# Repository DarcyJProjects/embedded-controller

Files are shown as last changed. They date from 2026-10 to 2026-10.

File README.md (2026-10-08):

# Industrial Automation Embedded Controller

### Introduction

This project was a deep dive into 4-layer PCBs, galvanic isolation, strict EMI filtering, and mixed-signal design with the goal to create a robust, industrial-style controller from scratch.

Built around an STM32 Cortex-M4, this embedded controller handles galvanically isolated field I/O using a custom DMA-driven MODBUS RTU stack. It also features a "no-code" automation engine, letting you configure logic remotely via a web panel.

I've implemented several hardware features including an RTC with battery backup, HMI OLED, microSD logging, an EEPROM, efficient multi-stage power distribution & conversion with real time power monitoring, as well as many protection features.

The entire project - the custom PCB, schematics, firmware, and web panel - is completely open-source, so feel free to look into it and see how it works!

IMG: Main

<p>
  This project is open source hardware under the <strong>CERN Open Hardware Licence Version 2 - Strongly Reciprocal (CERN-OHL-S v2)</strong>.
</p>
Open Source Hardware Logo

The editable hardware source files are provided so that the design can be studied, modified, and manufactured in accordance with the licence.

⚖️**Disclaimer:** *This hardware is a personal engineering project created solely for **educational purposes and skill development**. While it explores industrial design techniques, it has not been tested against or certified for any specific industrial standards (e.g., IEC, UL, CE). It is provided ”AS IS” without warranty. For full licence details, design files, and terms of use, please see the **[licence section of this document](#licence)**.*

---

## Table of Contents

* [Demo](#demo)

* [Features & Specifications](#features--specifications)

* [Hardware Architecture & Schematics](#hardware-architecture--schematics)

* [How It Works](#how-it-works)

* [Why I Built This](#why-i-built-this)

* [Firmware & Web Panel](#firmware--web-panel)

* [Repo Structure](#repo-structure)

* [Licence](#licence)

* [Safety Disclaimer](#safety-disclaimer)

* [Acknowledgements](#acknowledgements)

* [Feedback & Contributions](#feedback--contributions)

---

## Demo

For the demo, I mounted the controller on a DIN rail and wired it into a small irrigation-style test rig. The goal was to demonstrate as many parts of the board as possible, including relay outputs, digital inputs, analogue voltage signals, 4-20 mA current loops, and MODBUS-based monitoring/control.

Watch Here ➡️: [STM32 Embedded Controller Demo - YouTube](https://www.youtube.com/watch?v=2GqDx222arY)

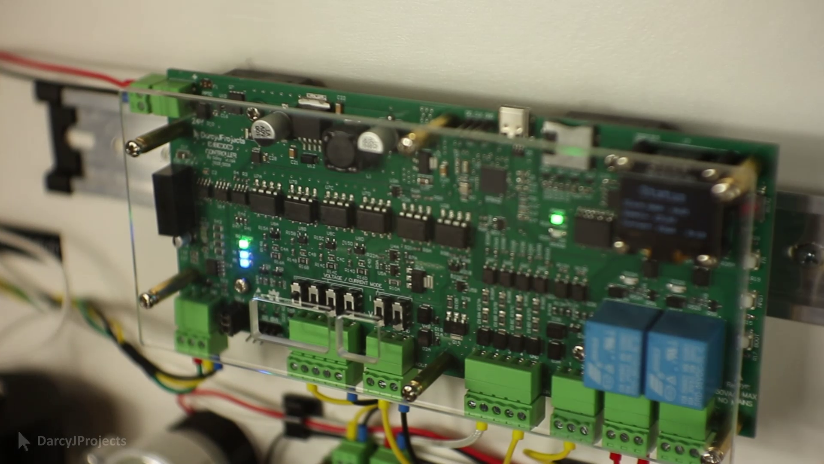
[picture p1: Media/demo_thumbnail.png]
IMG: PCB


I also designed a 4-20 mA transmitter board for this demo converting a 0-3.3V signal to a current loop: [Designing a 4-20 mA Transmitter - DarcyJProjects](https://darcyjprojects.xyz/index.php/2026/05/25/designing-a-4-20-ma-transmitter/)

---

## Features & Specifications

I tried to pack a wide range of industrial-style hardware and firmware features into this controller so I could learn as much as possible across the realms of PCB design, embedded firmware, power electronics, isolation, and automation protocols.

IMG: PCB

### **Core Specifications:**

- **Core:** STM32G431 Cortex-M4 MCU running at up to 170 MHz
- **Power input:** 7-28 V DC input range
- **PCB:** Custom 4-layer PCB with separated logic and field domains
- **Protection:** Reverse polarity protection, over-current protection, TVS protection, and ESD protection
- **Isolation:** Galvanic isolation between the logic side and field-side interfaces
- **Memory:** 4 KB EEPROM with CRC-backed configuration and automation rule storage
- **Connectivity:** Isolated RS485 for MODBUS RTU, plus USB-C for DFU flashing and serial debugging
- **Control:** Web panel with custom "no-code" automation rules and MODBUS register access
- **Local interface:** OLED display, tactile buttons, status LEDs, and hardware mode switches, on-board configuration factory reset
- **Expansion:** Isolated I²C header for supported field-side peripherals

**A more detailed outline can be found in the 10-page datasheet [here](https://github.com/DarcyJProjects/embedded-controller/blob/main/Documentation/datasheet/datasheet.pdf).**

### Isolated Field I/O:

| Interface | Channels | Electrical Specification | Description |
|:--- |:---:|:--- |:--- |
| **Analogue Inputs** | 4 | 0–5 V or 4–20 mA | 12-bit ADC; Per channel switch for Voltage & Current Mode |
| **Analogue Outputs** | 2 | 0–5 V or 4–20 mA | 12-bit DAC; Per channel switch for Voltage & Current Mode |
| **Digital Inputs** | 4 | 24 V DC signalling | Optocoupler-isolated industrial binary inputs |
| **Digital Outputs** | 2 | 24 V DC load rated | Galvanically isolated low-side sinking drivers |
| **Relay Outputs** | 2 | 30 V DC / 50 V AC (ELV)  | SPDT mechanical relays |
| **I²C expansion header** | 1 | Isolated 3.3 V / 5 V I²C | Allows supported external devices to be mapped into the MODBUS register space with custom firmware drivers |

### Power:

- Buck Converter for High Efficiency 24 V to 5 V conversion
- Linear Regulator for a clean 3.3 V supply to the MCU
- Switching Isolation Power Supply to power the field side circuitry
- PPTC Fuses, "Ideal Diode" Reverse Polarity Protected Input

### On Board HMI:

- 0.96" OLED display
- 4x tactile buttons for menu navigation, reset, DFU entry, and factory reset
- Status LEDs for power, isolated power, communication, relay state, and general status
- Hardware mode switches for analogue current/voltage configuration

### Overall Block Diagram:

IMG: Block diagram

### Power Supply Block Diagram:

IMG: Power Supply Block Diagram

---

## Hardware Architecture & Schematics

To maintain readability and to provide reusability of designs, the hardware is structured hierarchically in Altium Designer rather than using a single flat schematic.

### Hierarchical Design Breakdown

The design is partitioned into 1 top-level sheet and 15 modular sub-sheets:

- **Main:** Connects all subsheets together, reuses I/O designs for multiple channels, and attaches connectors.
  
  - **I2C_Isolator:** I2C header with ISO1540 isolator, TVS protection
  
  - **AOut_Isolator:** Reusable 3.3V to isolated 0-5V/4-20mA analogue output channel with NSI1200 isolator, TVS protection
  
  - **DOut_Isolator:** Reusable 3.3V to sinking 24V digital output channel with LTV-356T optoisolator, TVS protection
  
  - **I2C_RTC_DS3231:** On-board DS3231 Real Time Clock and clock battery
  
  - **AIN_Isolator:** Reusable isolated 0-5V/4-20mA analogue to 3.3V input channel with NSI1200 isolator, TVS protection
  
  - **STM32_MCU:** STM32G431CBU6 microcontroller with USB DFU, filtering, SWD, status LEDs and BOOT & NRST buttons. TVS diodes on USB & SWD lines
  
  - **Power_Supply:** PPTC Fused 24V input through "ideal diode" reverse polarity protection through 24 to 5V buck converter, branching to 3.3V linear regulator for logic side power and a PPTC fused 5V DC-DC isolation power supply for the field side. Features TVS diodes on 24V input and 5V field side output of DC-DC converter
  
  - **RS485:** MAX485 Transceiver with dual CA-IS3722 Isolators, status LEDs, biasing and termination header, TVS protection
  
  - **I2C_PowerMonitor_INA226:** INA226 power monitoring IC for the 24V input post reverse polarity protection but pre buck converter
  
  - **I2C_EEPROM_AT24C32:** AT24C32BN EEPROM used for automation rule and configuration storage
  
  - **I2C_Display:** Socket for the 0.96 inch OLED display module, Menu button
  
  - **BTN2_FactoryReset:** Factory reset button
  
  - **SPI_SD:** MicroSD card slot with TVS protection on all data lines
  
  - **DOut_Relay:** Reusable SPDT relay with coil switched to isolated 5V supply via LTV-356T optoisolator, status LED, flyback suppression
  
  - **DIn_Isolator:** Reusable 24V to 3.3V digital input channel with LTV-356T optoisolator, TVS protection

**Schematics:** View the complete 16-sheet schematic here: [Documentation/schematics](https://github.com/DarcyJProjects/embedded-controller/blob/main/Documentation/schematics.pdf)

### Galvanic Isolation Separation

The PCB features a continuous galvanic isolation barrier running through all 4 layers:

- **Domain Partitioning:** The logic ground (`GND`) and the isolated field ground (`5V_ISO_GND`) are never connected together nor overlap or share ground planes.

- **Physical Barrier:** A continuous non-copper clearance barrier splits the PCB in two from top to bottom, offering the logic side a protective barrier from field side HV transients.

- **Over the Barrier:** No traces cross the barrier without isolation by dedicated isolation ICs or optoisolators.

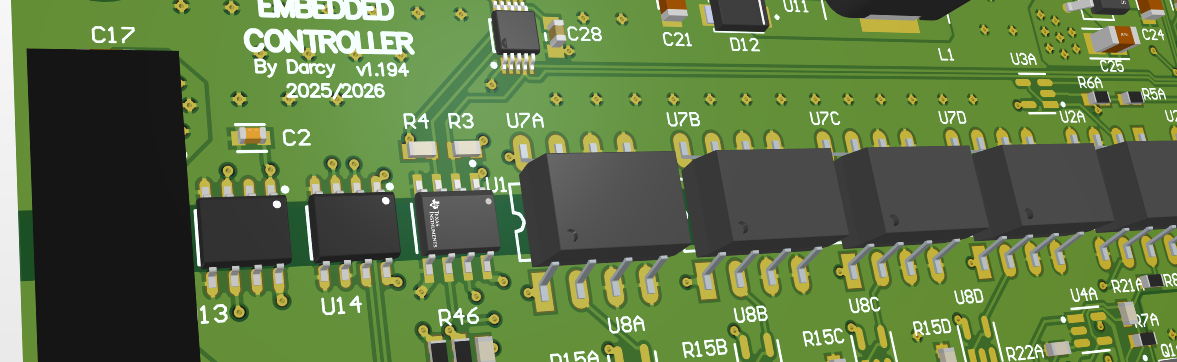
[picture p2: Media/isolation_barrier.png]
Isolation Barrier Image


---

## How It Works

The controller is split into two main electrical domains:

1. **Logic Domain:** STM32G4 MCU, EEPROM, OLED, RTC, buttons, USB-C DFU, isolated signals coming from the I/O isolators, etc.

2. **Field Domain:** I/O Inputs and Outputs, Relays, RS485, Isolated I²C expansion header

These two domains are separated by a galvanic isolation barrier. If you look at the PCB, you can actually see a moat separating the two sides copper pours.

The field side is powered through an isolated 5V DC/DC converter, and the signals that cross the barrier use appropriate isolators depending on the interface (capacitive, optical, etc).

### MODBUS register model

The firmware exposes the controller's I/O through a MODBUS register map:

- **Discrete inputs** for digital input states
- **Coils** for digital outputs and relay outputs
- **Input registers** for analogue input readings
- **Holding registers** for analogue output setpoints

There are also **virtual registers**, which can be created dynamically and used as intermediate values in the automation logic. This is useful for when you need to link many rules together for more complex automation logic.

### Custom automation engine

One of the main firmware features is the local automation engine. Instead of reflashing the STM32 every time you want to update its configuration or more importantly its automation logic, rules can be configured directly over MODBUS using custom vendor-defined (that's me!) function codes.

The idea is to make the board behave a little more like a tiny configurable PLC. A rule can read an input, compare a value, update an output, or write to a virtual register. Once configured, the STM32 runs the logic locally.

### Hybrid MODBUS master/slave concept

The firmware is also designed around a hybrid MODBUS architecture allowing the controller to act as both a master and slave at the same time. The controller can report data to an upstream system while also communicating with downstream MODBUS devices.

For instance, [I reverse engineered an RS485 SHT30 sensor](https://darcyjprojects.xyz/index.php/2025/07/08/reverse-engineering-a-cheap-sht30-rs485-modbus-sensor/) used for reading temperature and humidity. By connecting this to the RS485 line of the embedded controller, it can read from the sensor over MODBUS (as a master to the slave sensor) while also reporting information requested back to the web panel (as a slave to the master web panel). 

This was mainly an experiment in building something more flexible than a fixed slave board, while still keeping the system simple enough to understand and debug.

IMG: Web Panel

---

## Why I Built This

This project was a major undertaking compared to my earlier electronics projects, integrating mixed signal design, complex isolation barriers, and low level C protocol implementation. I wanted to build something that forced me to deal with more realistic embedded hardware problems, relevant to industrial, mining, manufacturing and remote monitoring environments.

### What I learnt: hardware

- 4-layer PCB design
- Altium Designer workflow
- Mixed-signal PCB layout
- Analogue and digital galvanic isolation
- Isolated power supply design
- 24 V field input and output circuitry
- 4-20 mA current-loop inputs and outputs
- RS485 physical-layer design, termination, and biasing
- Relay output design and low-side switching
- Protection circuitry using PPTC fuses, TVS diodes, and MOSFET-based reverse polarity protection
- Rail-to-rail op-amp circuits for buffering, scaling, and signal conditioning
- Debugging real PCB mistakes using trace cuts, enamel wire, and a lot of patience
- Parasitic impedance and what it does to buck converters!

### **What I learnt: Software**

- STM32CubeIDE and STM32G4 firmware development
- Writing a MODBUS RTU stack from scratch
- Using DMA so communication does not block the CPU
- Building drivers for EEPROMs, RTCs, OLEDs, and other peripherals
- Storing configuration data with CRC checks
- Designing a small rule engine for local automation logic
- Mapping physical and virtual I/O into a MODBUS register model
- Building a Node.js web panel to configure and monitor an embedded device
- How to use LaTeX to write documentation

IMG: Prototyping

---

## Firmware & Web Panel

### Firmware Flashing

The firmware is built in STM32CubeIDE for the STM32G431CBU6 and can be uploaded to the Embedded Controller via the USB-C port:

1. Ensure the board is powered via an external 24V DC supply. The USB connector provides no power, so the external supply is necessary.
2. Connect to the board using a USB-C cable.
3. Enter the bootloader by holding `BOOT0` , pressing/pulsing `NRST` once, and then finally releasing `BOOT0`.
4. Flash the compiled binary directly over USB DFU using STM32CubeProgrammer or a similar utility.
5. Connect over serial/MODBUS via the RS485 line for configuration.

### Web panel

The Node.js web panel connects via a USB-to-RS485 adapter to interface with the embedded controller over MODBUS. It can be installed like so:

```bash
cd "Web Panel"
npm install
npm start
```

Open the local address shown in the terminal in a web browser. Connect to the RS485 line with a USB-to-RS485 converter and select its Serial COM port.

---

## Repo Structure

```text
stm32-plc-project/
├── Documentation/              # Datasheet, drawings, PDF Schematics
├── Firmware/                   # STM32CubeIDE firmware project
├── Hardware/                   # Altium Designer project: PCB design files, Altium schematics
├── Web Panel/                  # Node.js web configuration panel
├── Media/                      # Photos, renders, screenshots, and demo images
├── LICENCE-CERN-OHL-S-2.0.txt  # CERN-OHL-S v2 licence text for hardware
├── LICENCE-MIT.txt             # MIT licence text for software
└── README.md                   # this file!
```

---

## Licence

This repository contains both hardware design files and software.

### Hardware

The hardware design files are licenced under the **CERN Open Hardware Licence Version 2 - Strongly Reciprocal (CERN-OHL-S v2)**.

This applies to the PCB design files, schematics, hardware source files, mechanical drawings, and other files required to study, modify, manufacture, and distribute the hardware design.

You are free to:

- **Study** and **modify** the design
- **Make** your own copies
- **Distribute** modified versions, as long as you follow the licence terms

In general, the strongly reciprocal licence means that modified versions of the covered hardware design must also be shared under the same licence, with attribution and source files provided.

For the full legal terms, see [LICENCE-CERN-OHL-S-2.0.txt](https://github.com/DarcyJProjects/embedded-controller/blob/main/LICENCE-CERN-OHL-S-2.0.txt).

### Firmware and Software

Unless otherwise stated, the firmware and software in this repository are licenced under the **MIT Licence**.

This applies to the STM32 firmware and the web configuration panel.

For the full legal terms, see [LICENCE-MIT.txt](https://github.com/DarcyJProjects/embedded-controller/blob/main/LICENCE-MIT.txt).

### Third-Party Code and Resources

Some parts of this project make use of third-party open-source code and resources. These remain under their original licences and are acknowledged in the [Acknowledgements](#acknowledgements) section.

IMG: Close up

---

## Safety Disclaimer

This hardware is a personal engineering project created solely for educational purposes, experimentation, and skill development.  

Although it uses industrial-style design techniques, it has **not** been tested, approved, certified, or validated against industrial, safety, EMC, electrical, environmental, functional safety, or regulatory standards, including IEC, UL, CE, RCM, or any similar certification scheme.  

**LIMITATION OF LIABILITY:**

**THIS PROJECT IS PROVIDED "AS IS", WITHOUT WARRANTY OF ANY KIND, EXPRESS OR IMPLIED. TO THE MAXIMUM EXTENT PERMITTED BY LAW, THE COPYRIGHT HOLDER ACCEPTS NO LIABILITY FOR ANY DAMAGE, INJURY, DEATH, LOSS, NON-COMPLIANCE, EQUIPMENT FAILURE, DATA LOSS, BUSINESS INTERRUPTION, OR ANY OTHER ISSUE RESULTING FROM THE USE, MODIFICATION, MANUFACTURE, ASSEMBLY, DISTRIBUTION, OR ATTEMPTED DEPLOYMENT OF THIS DESIGN.**

Do **not** use this project in:  

- real industrial installations  
- safety-critical systems  
- mains-voltage systems  
- life-support, medical, automotive, aviation, mining, or hazardous environments  
- commercial products without proper engineering review, testing, certification, and regulatory approval  
- any system where failure could cause injury, property damage, environmental harm, financial loss, or unsafe operation  

Anyone using, modifying, manufacturing, or testing this design does so entirely at their own risk and is responsible for ensuring compliance with all applicable laws, standards, and safety requirements.

---

## Acknowledgements

- The datasheet for this project was created using the [LaTeX Datasheet Template by Petteri Aimonen](https://github.com/PetteriAimonen/latex-datasheet-template), which is licenced under the LPPL-1.3c licence.

- The firmware directly uses the [stm32-ssd1306 OLED display driver by afiskon](https://github.com/afiskon/stm32-ssd1306) for the SSD1306-based OLED display, which is licenced under the MIT licence.

- The MicroSD / FatFS implementation was helped by this tutorial kiwih: [An SD card over SPI using STM32CubeIDE and FatFS](https://01001000.xyz/2020-08-09-Tutorial-STM32CubeIDE-SD-card/).

- Some parts of the firmware were written early in the project while the hardware was still being tested on breadboards. I have tried to acknowledge all external resources used, but if I have missed anything, please let me know and I will be happy to add the appropriate credit.

---

### Feedback & Contributions

Feel free to fork, share, and build your own!

If you build one, adapt part of the design, or use it to help with one of your own projects, I would love to see it - tag me on [LinkedIn](https://www.linkedin.com/in/darcywdjohnson/).

---

Darcy @ [www.darcyjprojects.xyz](https://www.darcyjprojects.xyz)

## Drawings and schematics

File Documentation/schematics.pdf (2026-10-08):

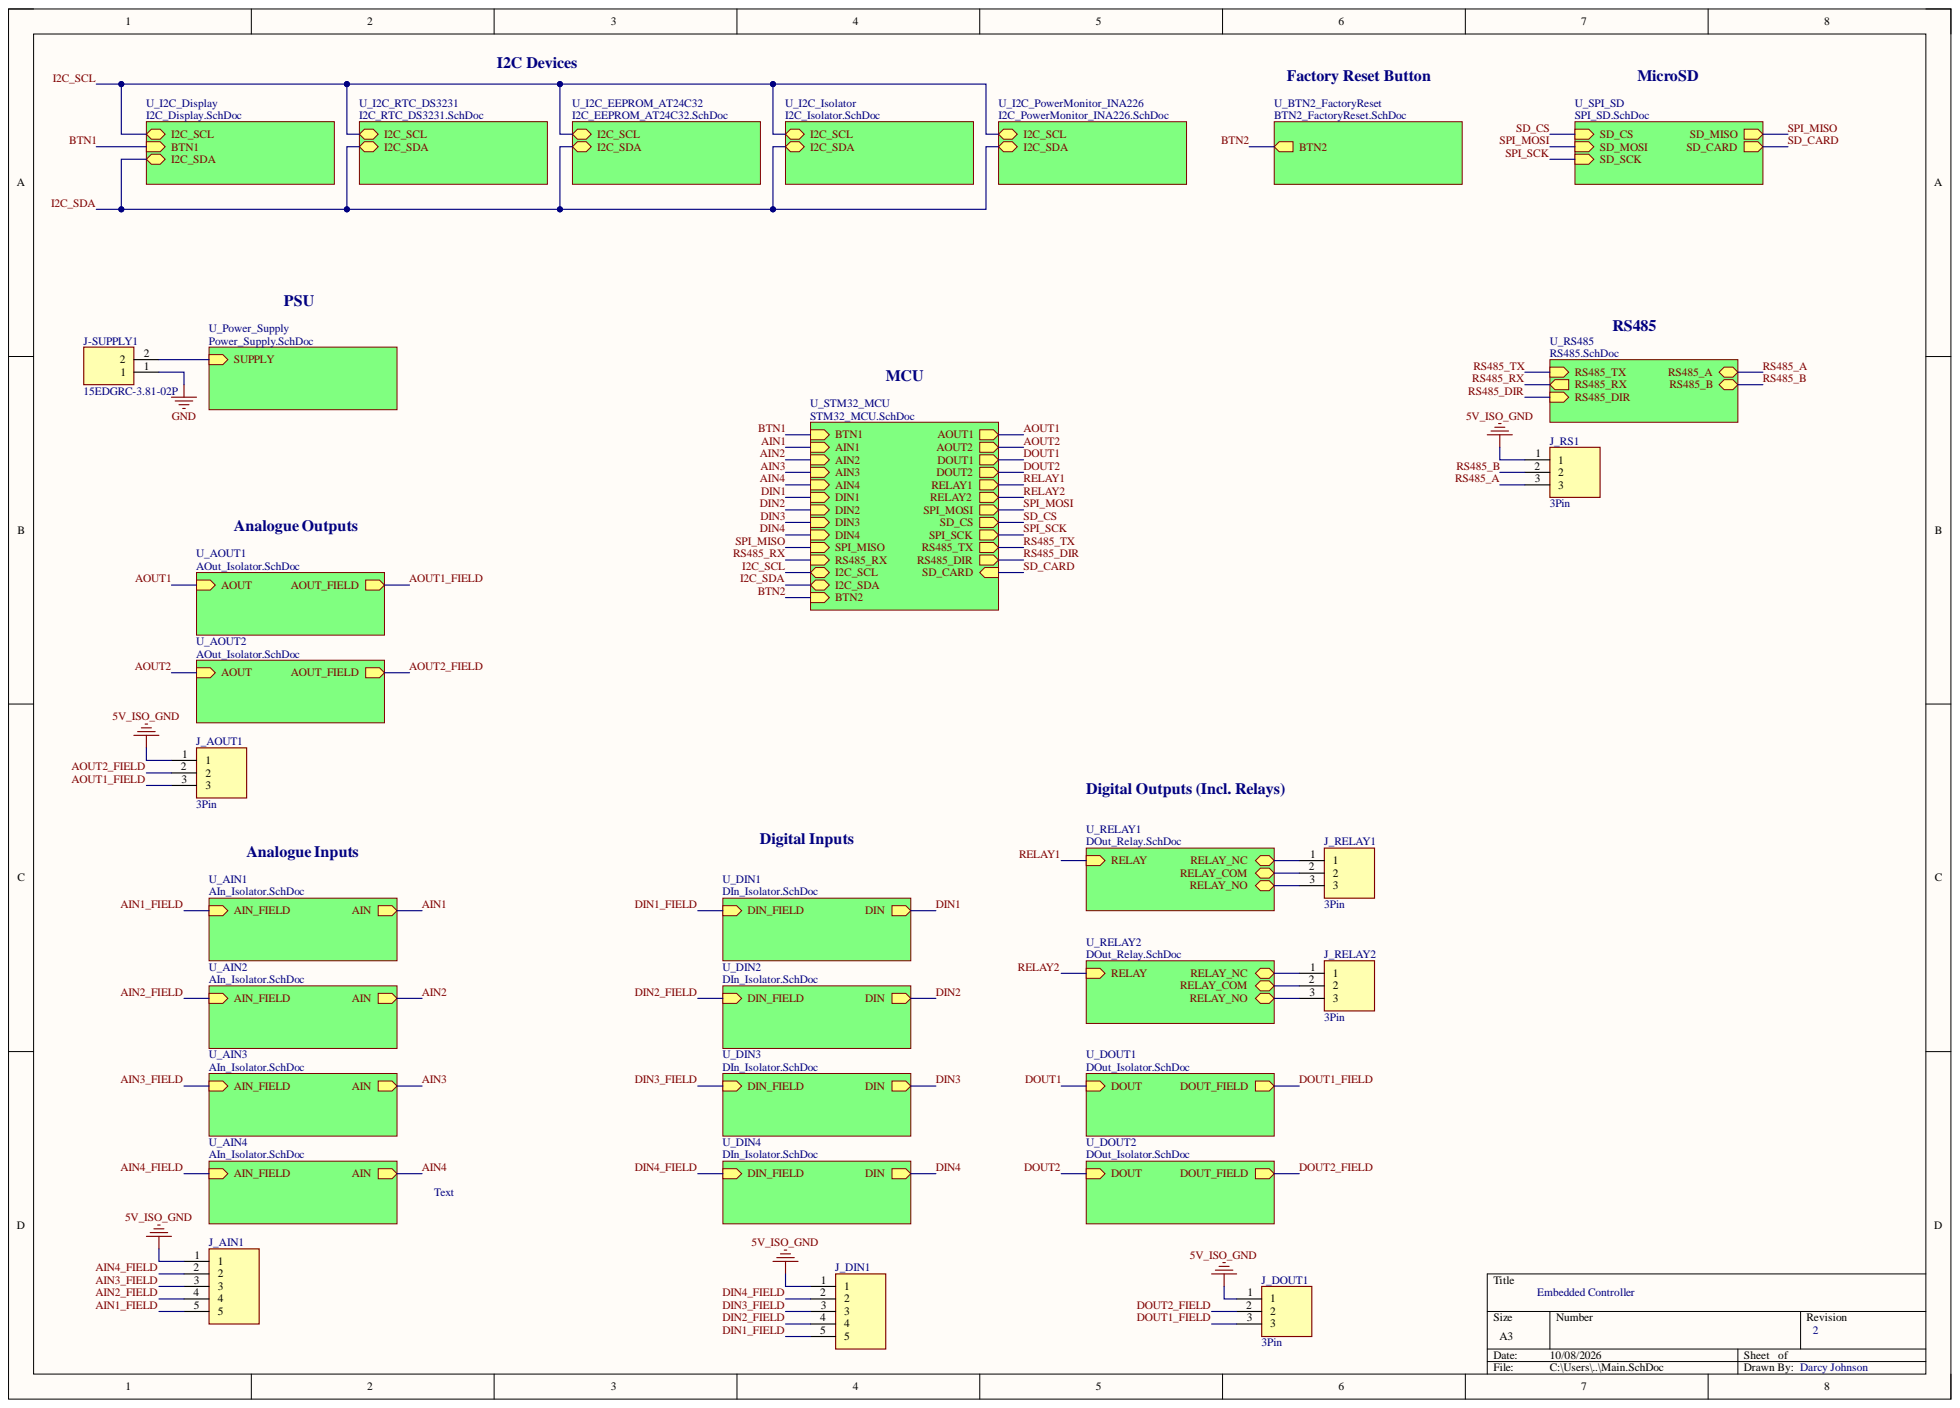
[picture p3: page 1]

Digital Outputs (Incl. Relays)

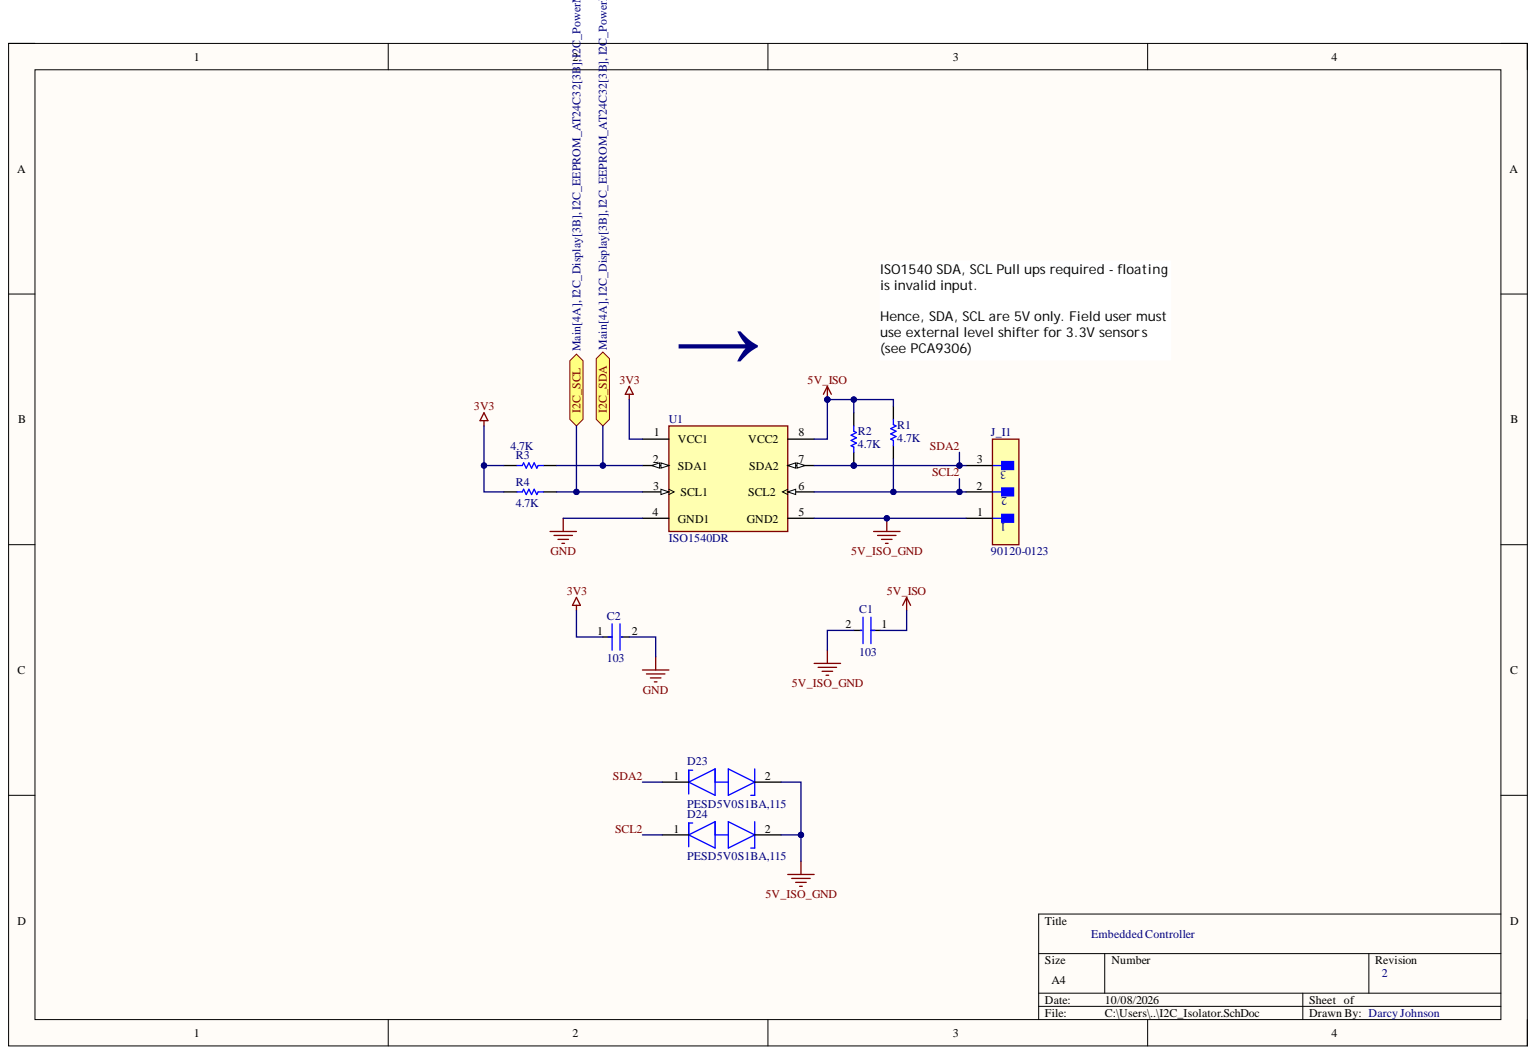
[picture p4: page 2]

ISO1540 SDA, SCL Pull ups required - floating
is invalid input.

Hence, SDA, SCL are 5V only. Field user must

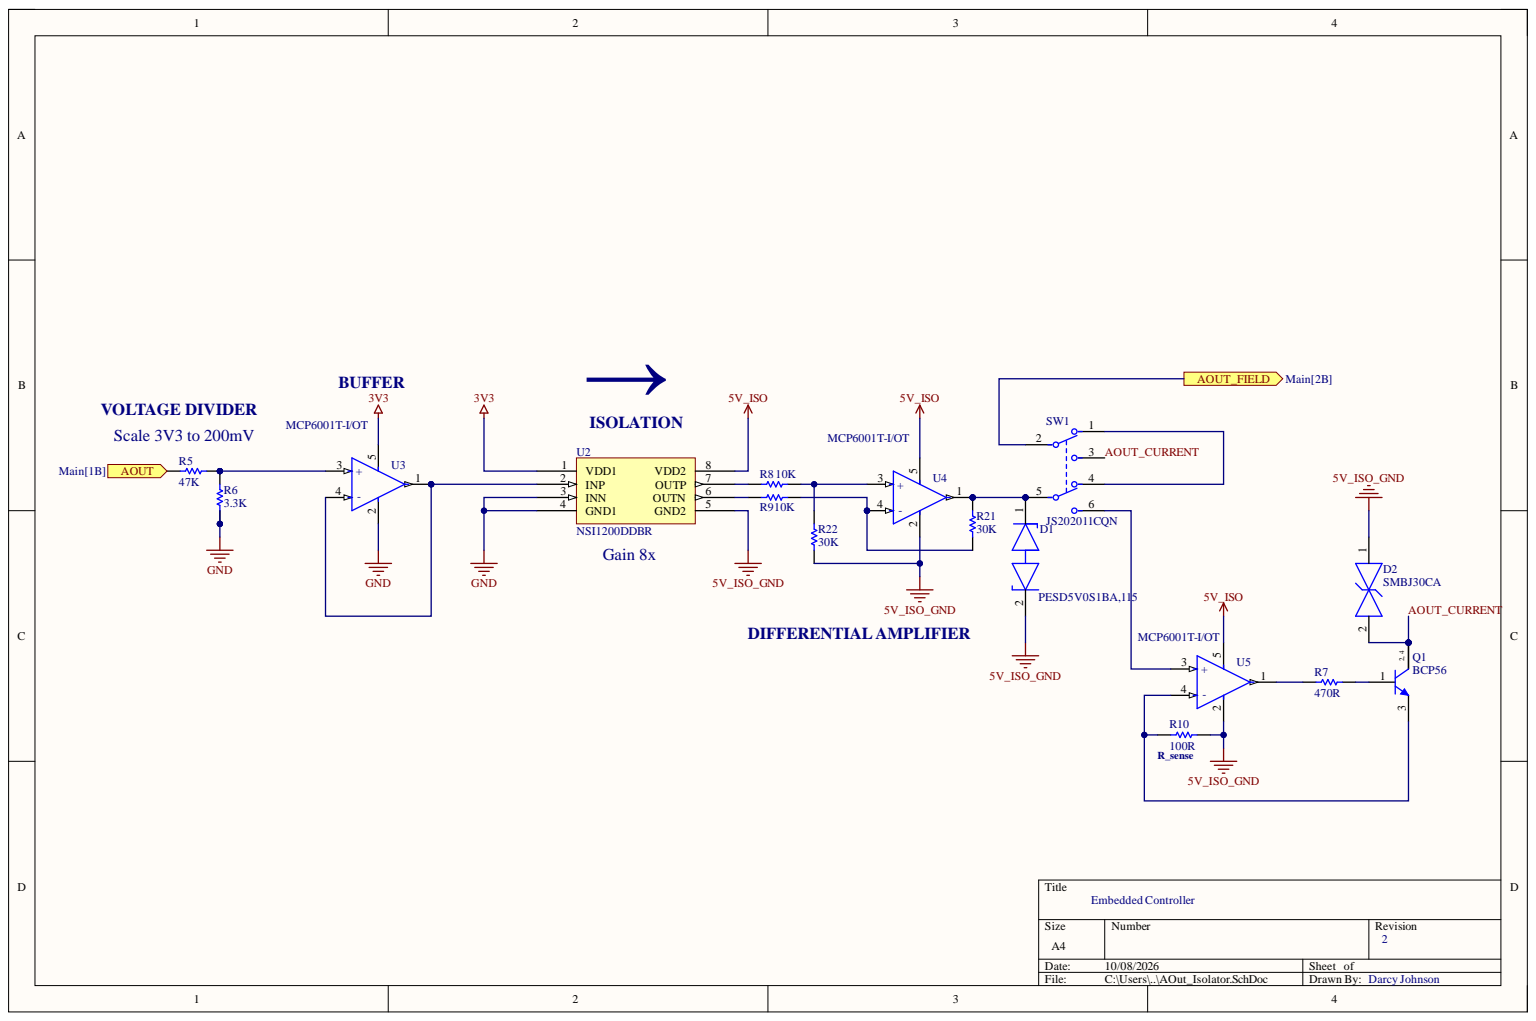
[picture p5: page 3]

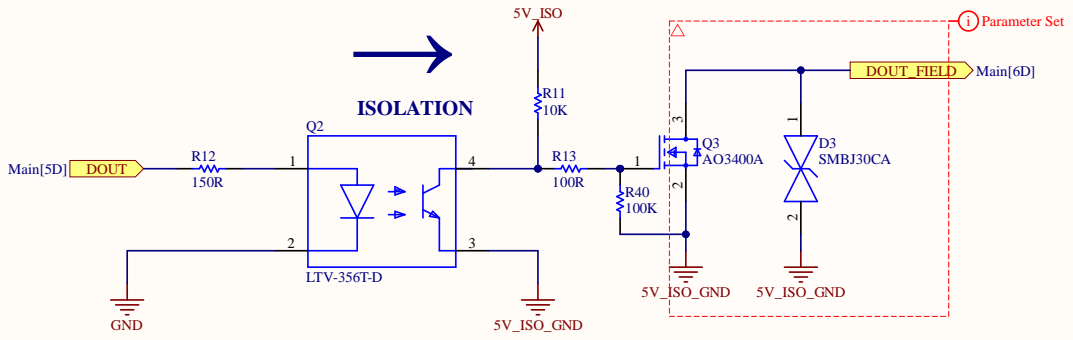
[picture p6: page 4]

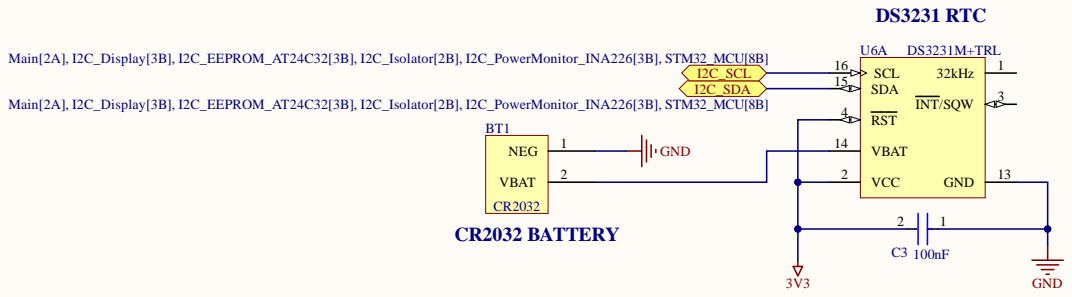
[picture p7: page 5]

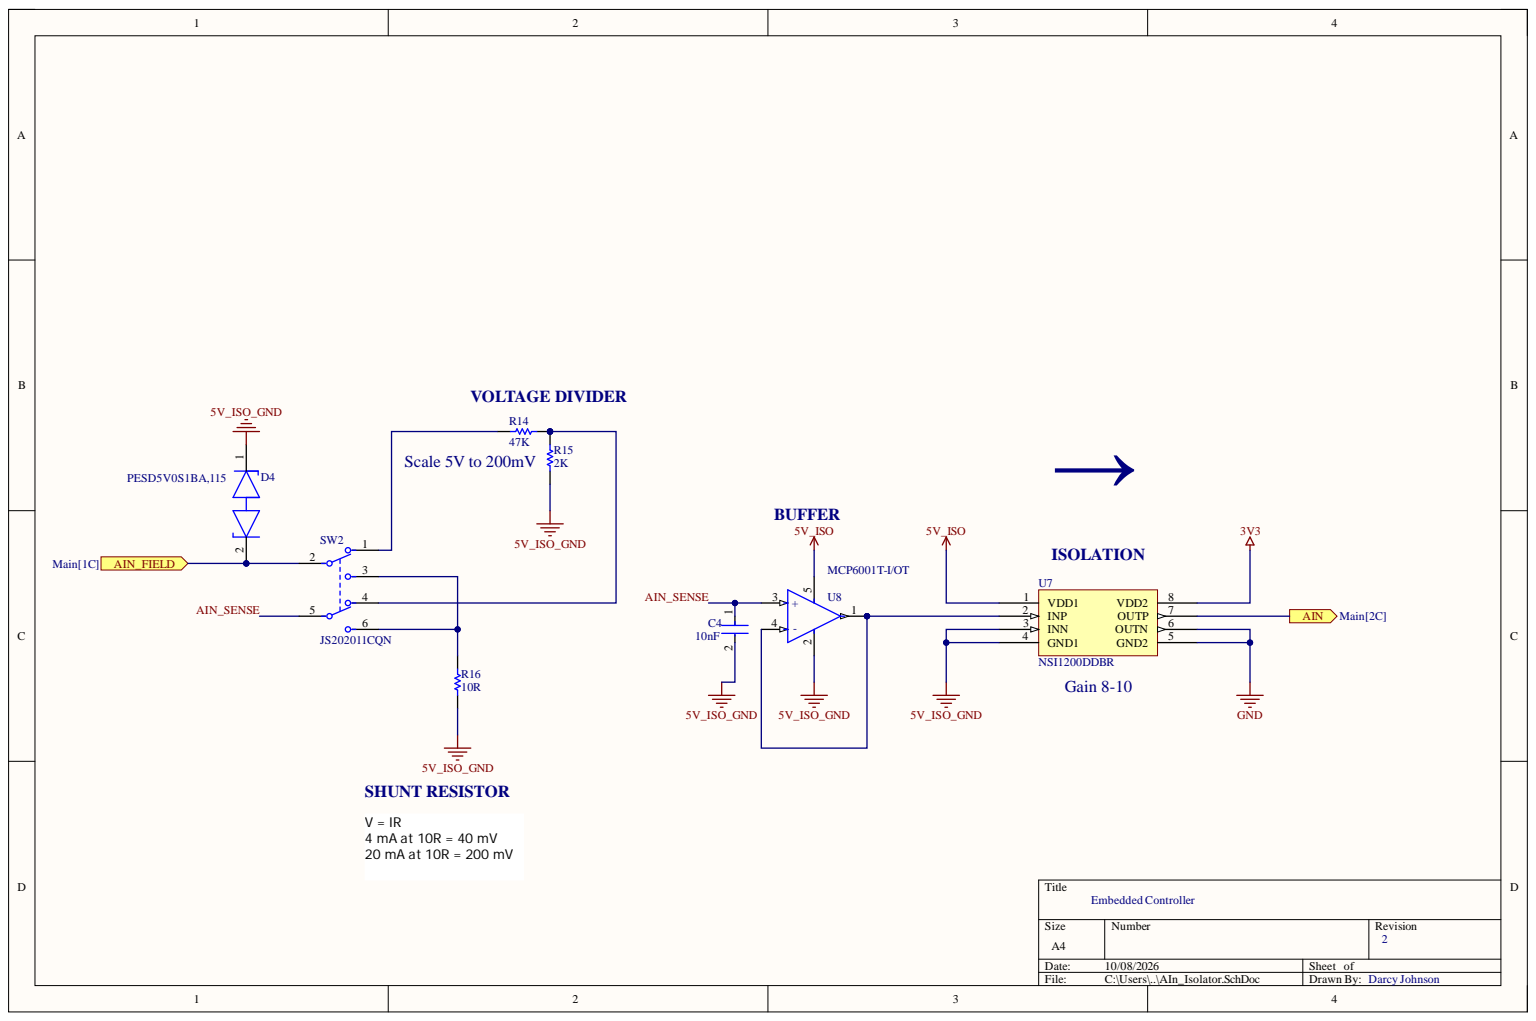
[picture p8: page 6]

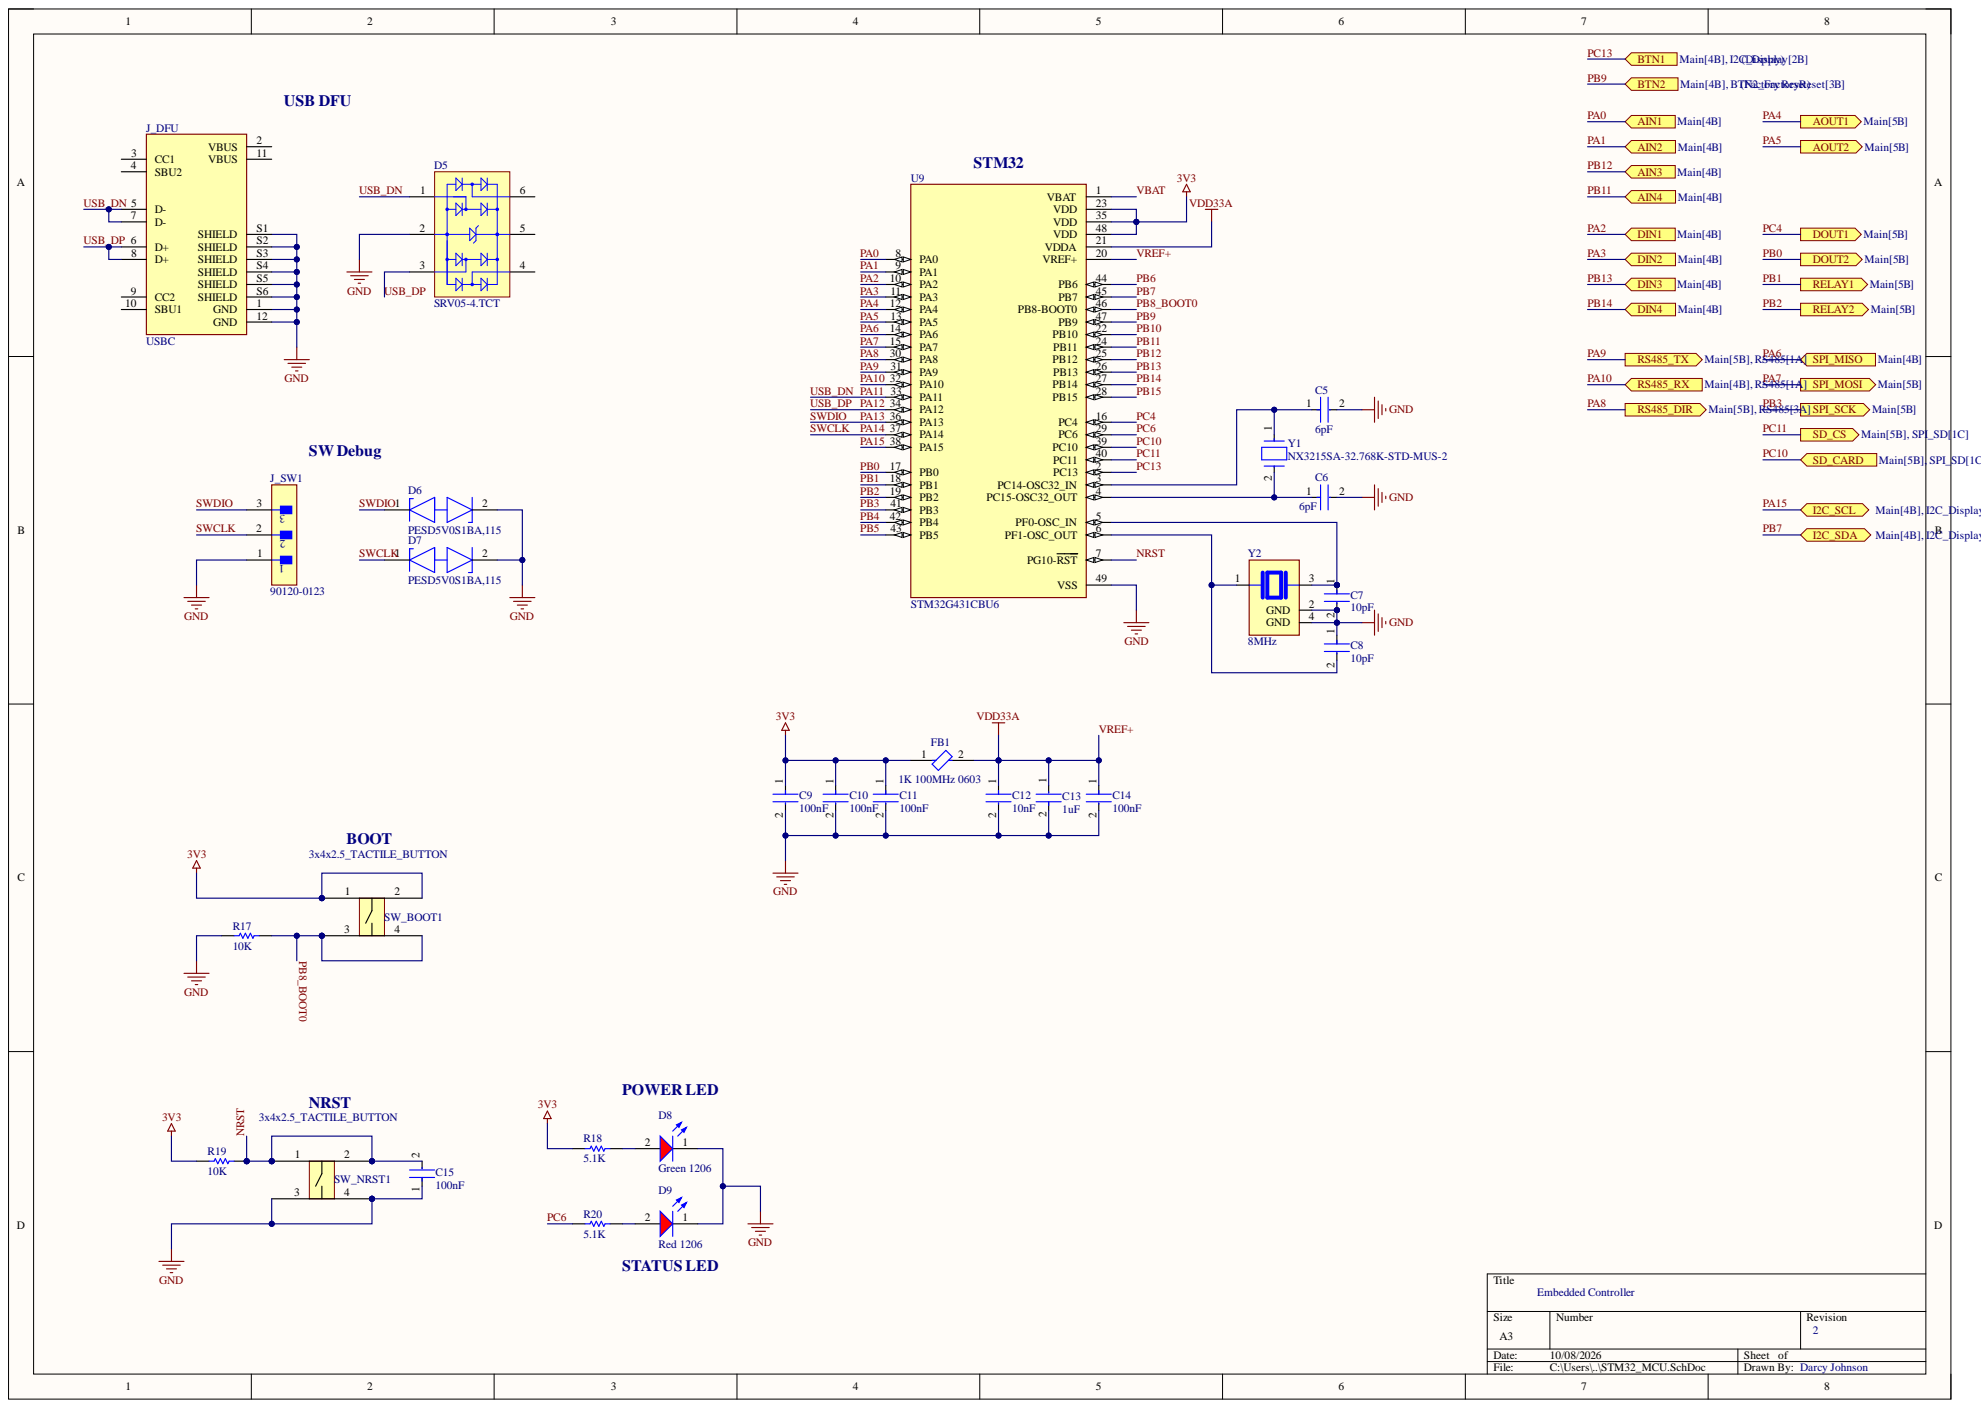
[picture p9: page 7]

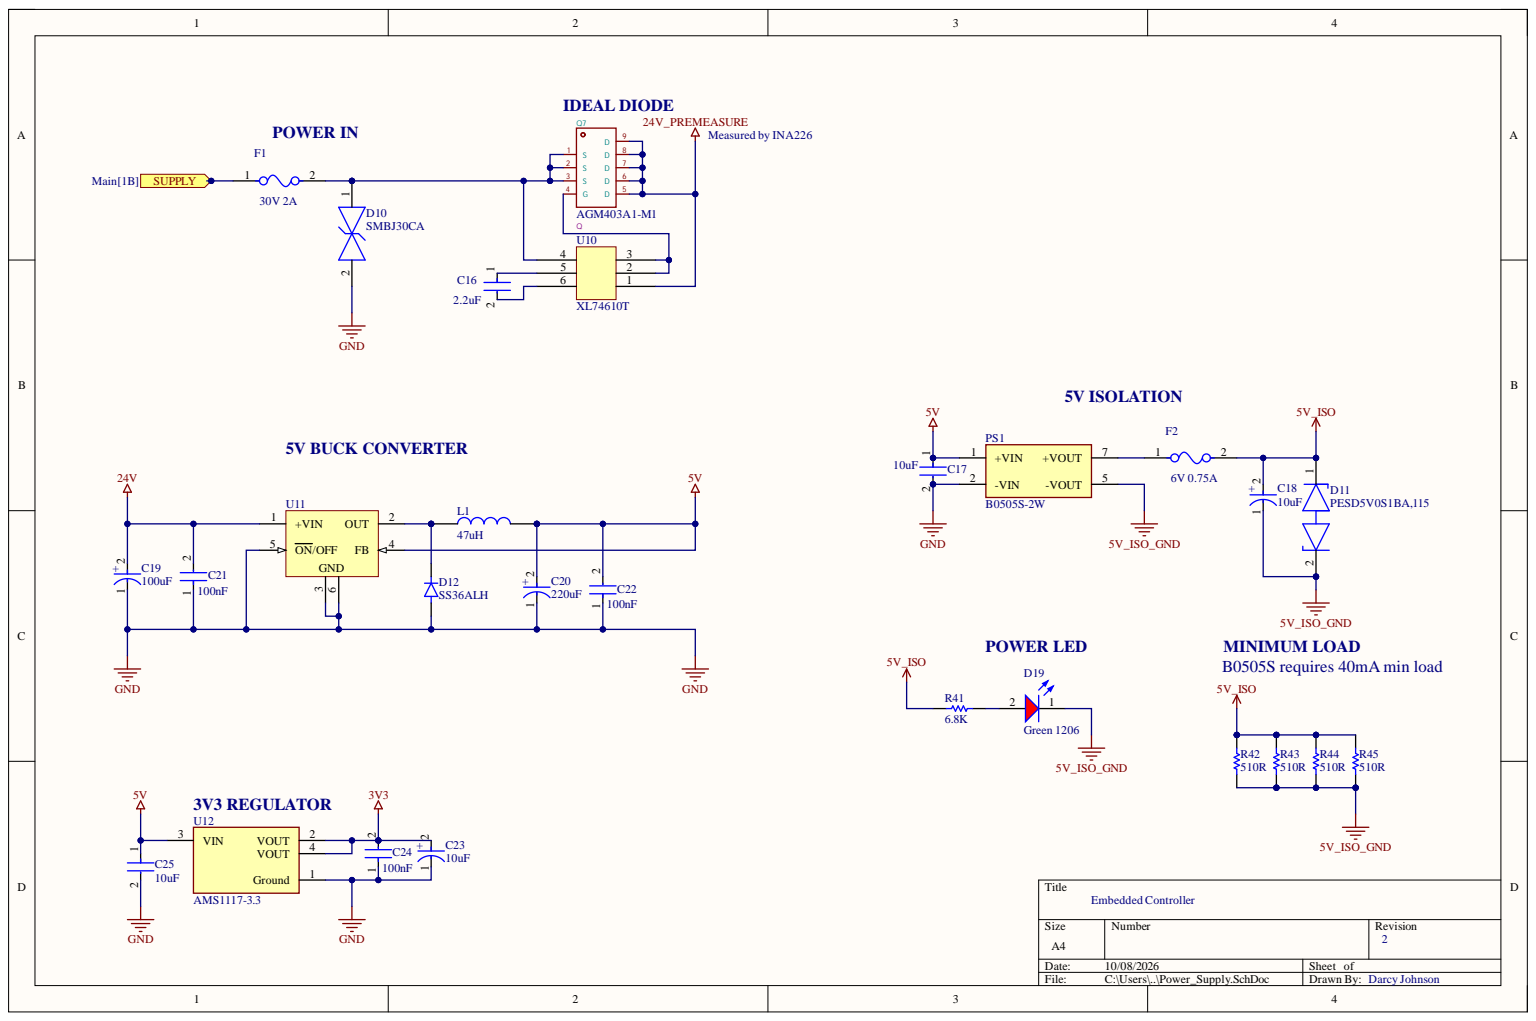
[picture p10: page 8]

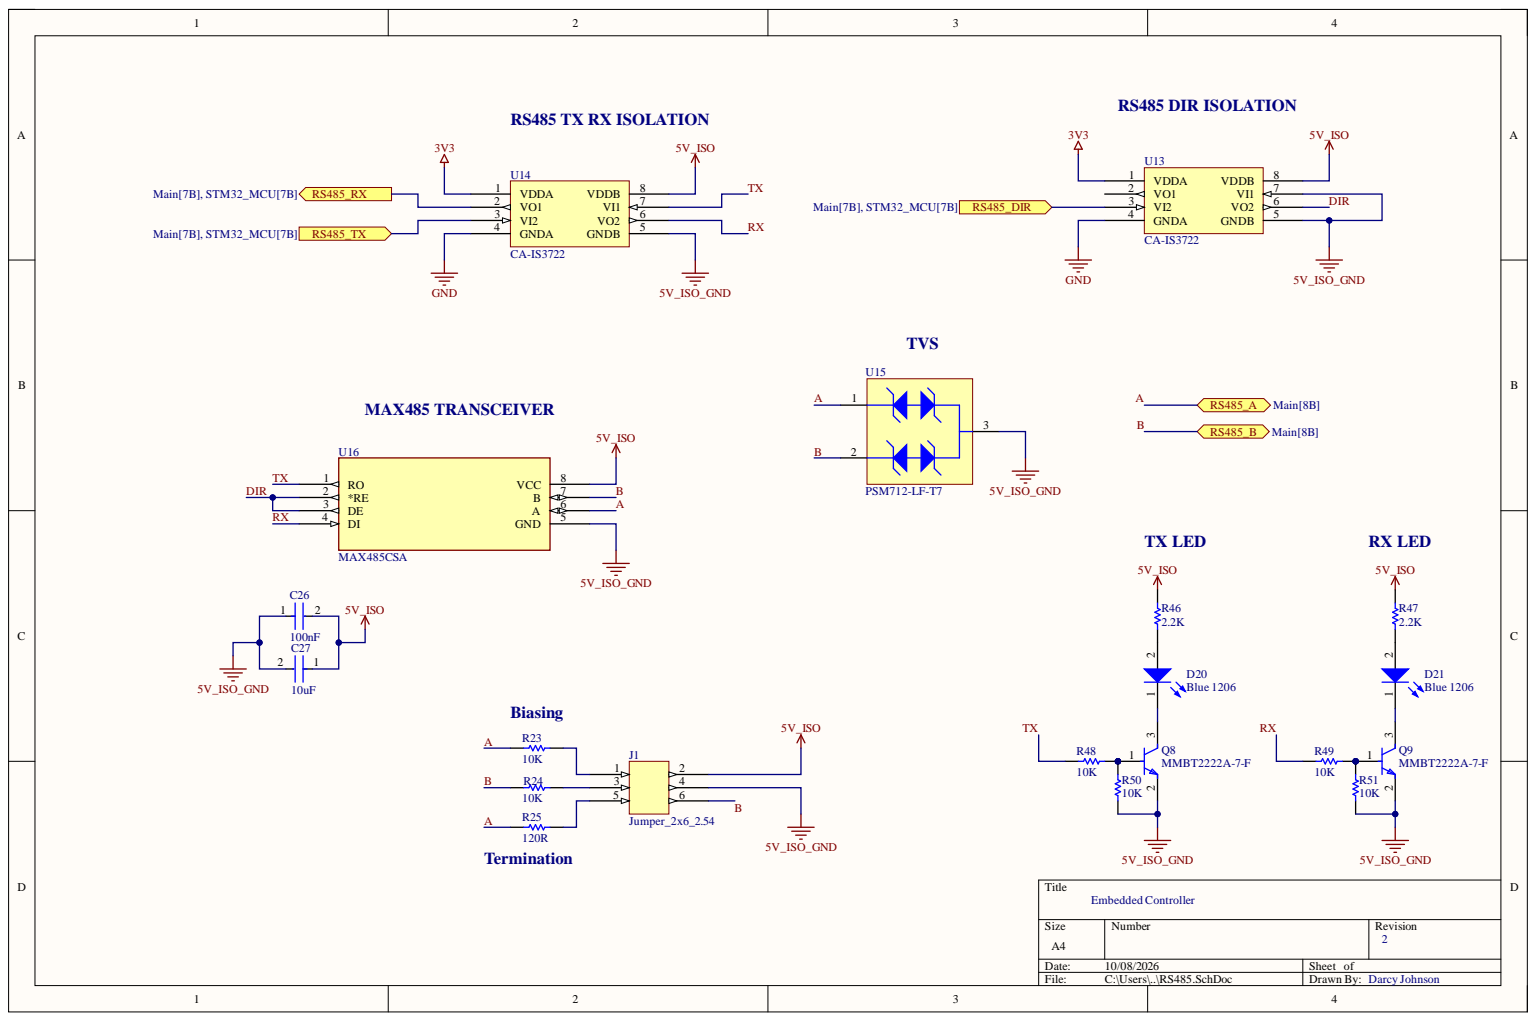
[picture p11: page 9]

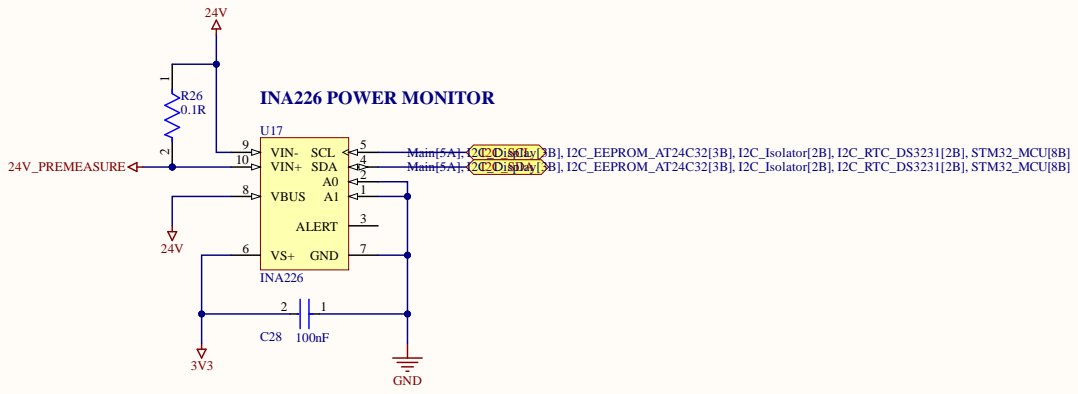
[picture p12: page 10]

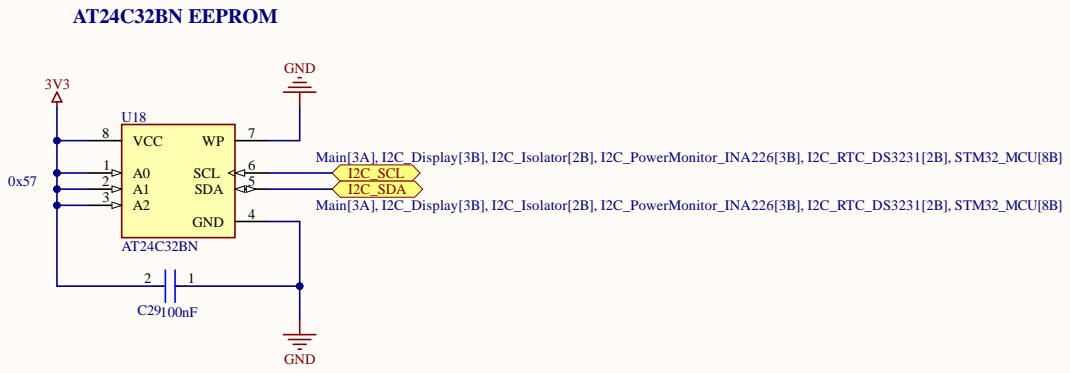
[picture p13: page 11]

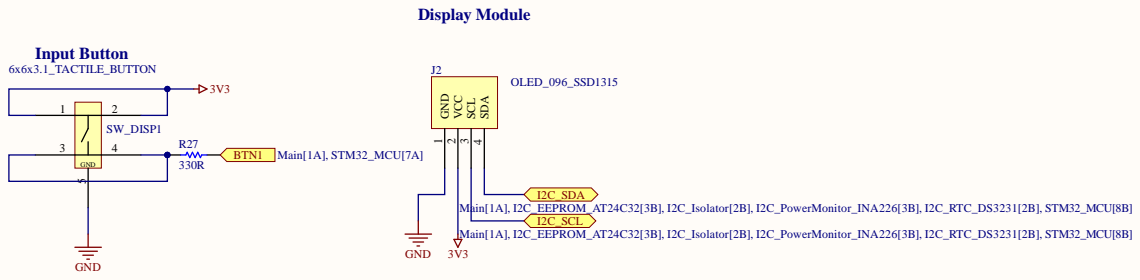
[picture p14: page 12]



G 1
G 2



Split series resistorsfor thermal margin*

1x 1206 can do 0.250 W so split evenly across two for
0.125 W each

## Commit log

2026-10-08 Minor Changes
    + Footprint updates, 3D model updates, Moving text around.
    + No major changes.
    [Main.PcbDoc, Main.PcbLib, Main.SchDoc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]
2026-10-08 Finalise Schematics
    + Removed progress note text
    + Populated title blocks
    + Exported schematics pdf
    [AIn_Isolator.SchDoc, AOut_Isolator.SchDoc, BTN2_FactoryReset.SchDoc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]
2026-10-08 ReadMe Updated
    + Added the demo video link
    + Added Hardware Architecture & Schematics section
    + Reworked Getting Started to Firmware & Web Panel section
